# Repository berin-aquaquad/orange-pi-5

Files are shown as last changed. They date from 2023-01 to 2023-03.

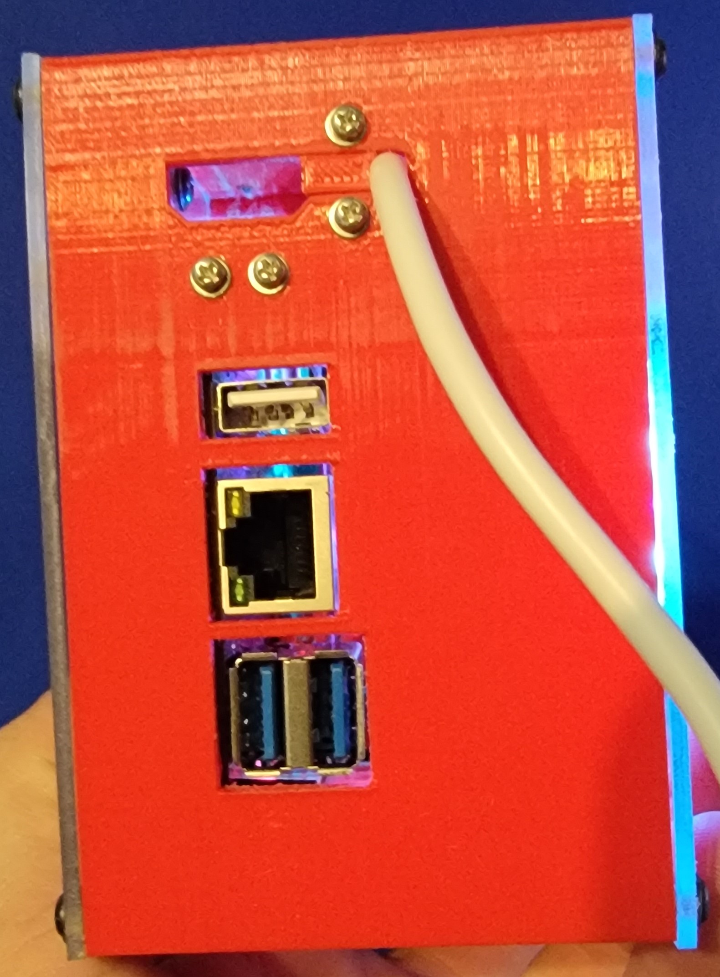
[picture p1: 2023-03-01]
design concept pipeline/20230228_231924.jpg

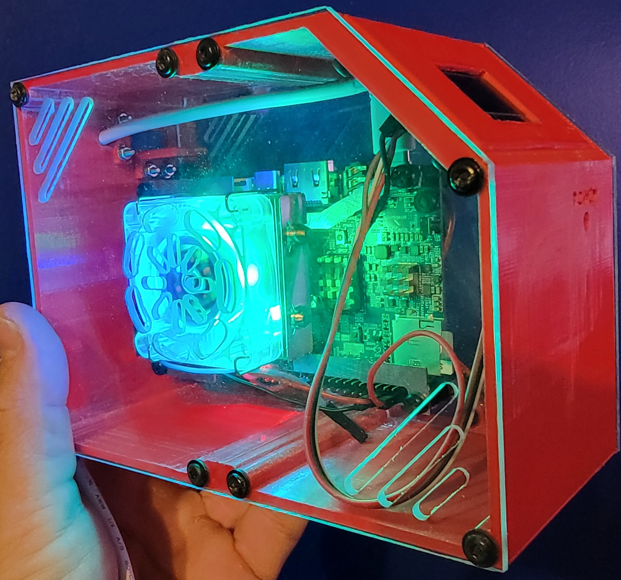
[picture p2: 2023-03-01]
design concept pipeline/20230228_231910.jpg

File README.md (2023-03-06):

Best source for current content from me https://forum.armbian.com/topic/25673-orange-pi-5-opi5-micro-desktop-case-design/

# As of right now this is a working design for anyone wanting to build the case. Everything matches up and everything works, questions PLEASE ask.

20230228_231910 thumb jpg 945669c564e5bb9a0a729d5997930626

# ORANGE-PI-5  I have updated the case with a new front half design, and many other adjustments.

# KEEP CHECKING BACK I UPDATE THIS GIT REPO OFTEN.

# FIRST OPI5 IN THE WORLD WITH A REAL MOUNTED ICE TOWER HEATSINK! Now that my OPI5 has a full suite of heatsinks on it. My next focus is on starting the build of the micro desktop case and OS. I believe the first part I'll build is the SBC mounting plane. That will give me something to mount to then I'll start the main body 3d print.

20230212_163206 thumb jpg 70dcd27b7984e3ebd21cffe2945fdb69

opi5microdesktopupdated2 thumb jpg 56bcd5c85741f7769b6156b93f30e681



opi5 micro desktop back and side view

opi5 micro desktop heatsink standoff mount bracket

opi5 micro desktop dimensions
The core body is 68mm wide. The lower standoffs are 6mm, the upper standoffs are 10mm

opi5 mounted to plane

OPI5 open micro desktop case design, with a split body for two options. Main feature printable on smaller cnc machines, second feature is the ablity to have custom front and back desgined panels. Some may need ports on the back of the shell. Other people may desire features like lcd(s) and headers that are on the back to be on the front. Its a more useful design.

2/18/2023 Bunch of updates and new features and corrections, standard filler for 45 degree area is done. This allows anyone to make a custom insert design, I have one design done so far which is the i2c lcd and a blank version. I have updated the side covers to remove the circle holes on one side and relocated the vent intake for the tower cooler on the other side. I have added a CR2032 BATTERY holder for RTC features. The battery holder is just a pocket for a real button battery holder. The idea is to solder wires and install it into the case holder All files affected by adjustments should be updated.

2/15/2023 I am redesigning the 45 degree area with a universal filler plate that can be designed to one's needs. I think at this point I'm going to add a folder as designs in the pipe for images only.

2/11/2023 So got my new 3d printer, ended up buying one from a big box office store, amazon lost the one I ordered delivering it to the wrong address?? I just printed the AFT half of the main micro desktop body. I have found a few things to be slightly off and am making cad corrections now. I'm also adding an insert filler setup that will allow the power cord to go though the aft of the case. I need to find the HDMI ribbon cable setup I used on an other project. (https://photos.app.goo.gl/GvprVxFfbKAWY7VR7 "raspberry pi fiberglass shell") I am doing some adjustments to the placement of the port openings and the ports drawn on the board are off slightly. I may post updates tonight. ******** 5pm update I've been cad'ing for the past few hours after taking my fam to the beach for a while, lot of fun but LOTS of Man o war littering the beach. updates should be uploaded around 11 ********** 11:14pm I believe I have uploaded all updated files.

2/6/2023 CAD files have been updated and uploaded, unless I missed something everything should be updated corrected with the latest corrections. .rsdoc .stl .dxf files and some images have been updated.

2/5/2023 I have milled the corrected back plane and it came out perfect see too pictures when I get to posting. Also I just discovered I made a small not error but over site. One of the back plane mounts is in the wrong location so you can not remove the back plane with the opi5 mounted IF that screw is populated. Because it is under the opi5 board under the stacked USB ports. I'm updating the cad drawing and I'll post the correction some time soon. That will be a correction to the master .RSDOC cad file, and to the back plane DXF file and the back half of the micro desktop tower shell dxf and .rsdoc files when I finish the correction. Look for all 3 files to have the same time date update when updated. If the git repo dates are not updated too today I have not updated yet.

2/4/2023 I have ordered a (https://www.amazon.com/gp/product/B076WXR8N9 "I2c OLED Display 0.96") and I just ordered a new much larger 3d printer. I will be making a custom front shell half version when I get the display. Again this case design is a modular setup so it can be custom to one's needs for the front and back halfs. As well as the width can be adjusted as desired.

2/3/2023 I have finally cut the side covers out of acrylic, I have posted the updated DXF files in the gcode folder as well as posting an image.

1/28/2023 Family visiting and other events and work sorry been quiet for a while. I have just finished a bunch of updates to the cad draws. Fine tuning to the measurements for the heatsink bracket and the mount plane hole spacing for the OPI5, and the mount hole placement of the OPI5 board its self. Sadly I can not find a picture with a measurements breakdown of the opi5 mounting holes. I have milled the back plane but the holes are just off by a hair, it looks good though.

1/22/2023 late tonight. I just updated the the cad files to fully realize the dimentions of the standoffs and other aspects. The CAD drawing should be a first version final draft as of now. The core body has been made a little wider. The core 3D printed body is now 68mm's wide. It was 62mms before getting the replacement standoffs. This also means the placements of the port openings for the OPI5 on the back of the case have been relocated by a few MM as well. JUST A REMINDER this case design is special. The shell is a split body for two reasons, different versions of the front and back halfs of the core micro desktop can be created. And the full sized case can be printed on smaller footprint 3d printers as small as a 110mm x 110mm print area.

1/22/2023 12:30pm ? I have done nothing I just tried turning the opi5 on one last time and it just randomly posted.... I am so confused right now I have done nothing changed nothing. I just plugged it in and it just posted and booted into the SD card ubuntu build???? WTF.... Odd thing is I'm getting no HDMI video but I am getting usbc-hdmi.... Well these problems have destoryed my chance to get anything done this weekend. To much time lost to total failure. About 2 hours after I stopped trying to turn it on, I came back to it and just plugged it in. The red light came on and it just started booting. I DONT GET IT.

* 1/22/2023 I have been endlessly overwhelmed by my employer. I was planning on starting to build parts for the case yesterday 1/21 SAT., but I was tasked with 
* designing and 3d printing. Inclusion mold parts for a many millions of dollars luxury yacht. That being said I just got a chance to test my opi5 today sunday. And I * apear to have a DOA dead unit out of the box. As of this moment this project is on hold indefinitely until I get a working OPI5. I am very angry and very pissed off. * My unit will not power on period, no signs of life nothing. Its 100% dead out of the box.

1/21/2023 I will be cutting the acrylic panel(s) today starting with the SBC mount panel first. I have not cut 1/8th acrylic on my cnc before so I may run into a bit of trial and error figuring the best milling bits out feeds/speeds.

1/16/2023 Ok looking for feed back https://www.amazon.com/Duttek-Degree-Extension-Motorcycle-Dashboard/dp/B08RRYMXB6 https://www.amazon.com/Poyiccot-Extension-Female-Extender-Straight/dp/B086YBP5VW Two examples of USB-C adapter which do you guys like? also USB-c to the front or back of the micro case? 
*************** This is the spacer/stand off kit I have purchased https://www.amazon.com/dp/B08DMSNB8X This is the kit for mounting the OPI5. All spacings will be based off of these when I get them. stay tuned. 6mm and 10mm standoffs are used from this kit. As well as one of the screws with two plastic nuts for holding the m.2 NVME drive.

1/17/2023 BIG update I have just mounted my heatsink to the OPI5 it LOOKS AMAZING. Now that I have my heatsinks mounted My next step is moving to to software.

1/15/2023 Unbelievable, I have to order a kit of plastic stand off mounts for the OPI5 project. I have a huge kit and its just ….. ? GONE ? In any case the brackets are built sanded and “dry” fitted. Its a perfect fit but still dont have the standoffs,so I cant assemble anything. Very pissed off, I’m 99.999999 sure I tossed the sorted box last year along with a bunch of trash and excess useless empty sorting boxes of like size kind. By design the bracket I designed and built clears everything. No feature on the OPI5 SBC is blocked between connectors and buttons.

1/14/2023 tonight, I found the screws I need FUI the cooler I described uses 2.5mm screws. I have picked up some 1/16th sheet steel and will try my hand and milling the brack design with my cnc. Its not designed for steel but is ok for aluminum. I do have some 4 flute bits so we shall see. **** tonight update part two, cutting steel sheet metal on my cnc machine...??..??? and its going REALLY well. I will post photos when the milling job is done. ******** last post for the night just before midnight. The steel frame bracket has been cut and is pictured in the cad/gcode folder have a look. Its the first noncad image I've posted.

1/14/2023 small update, my aluminum block has been cnc milled (I'll post new photos soon keep checking). I need to get some longer screws that match the heatsink and some sheet metal to create a bracket to keep the heatsink in contact with the processor (gravity strain relief). I wish I had access to a fiber or co2 metal cutting laser to make a perfect bracket. The standoff heatsink is to allow the small stick-on heatsink kit that adds cooling to the other chips on the OPI5. I also added a new folder with gcode files for the heatsink spacer block.

1/11/2023 Small update, finally got a chance to start building the aluminum spacer heatsinc block, I'll post pictures when able.

(1/7/2023) New updated cad drawing. I got my RPI4 "ice tower cpu cooling fan" heatsink. I have done the CAD adjustments I need for it to be installed. I am now creating a custom SPACER aluminum block and attachment bracket so it can even work with the OPI5. 
At this point if anyone has interest in adjustments Please contact me.

This is an ongoing project and I'll be uploading updated cad draws as they are available and pictures of the latest adjustments. If anyone has a request please send me a message via twitter #Berinmoney I'll respond as time allows. I'm also on orangepi.org forum and armbian forum. When I get closer to a final version I'll add images showing dimensions.

This design was created using Designspark mechanical https://uk.rs-online.com/web/generalDisplay.html?id=designspark%2Fdesignspark-mechanical 
I have not built the design yet as of the current date whatever today is. I will post about the start of the build when I start. I'm adding locations for all of the missing I/O to the shell as I find good parts to do so with, or learn of features. I just finished building the cad model 12/31/2022. I have currently left it as an open canvas design. The shell itself can be modified if so desired to be a mono body. Currently it's designed as a split body to be able to be printed on smaller 3d printers. The outside covers left and right are acrylic. The Mount that the OPI5 mounts to is acrylic as well. This design expects the two side panels and the sbc mount panel to be 3d printed or cnc cut or laser cut. The rest of the shell is to be 3D printed. Enjoy and please tag me as the original designer. 
FYI I'm looking for details on the OPI5. The OPI5 has an onboard RTC real time clock. and there are two test pads next to it one "grd1" the other "RTC1". That MUST be for a battery backup. I can find no details on what kind of a battery setup is needed. According to the schematic "RTC1" will be HOT with 5v DC when the SBC is running. What battery setup may be used on this? Any help would be wonderful.

Planned design additions for consideration: I need feedback on the listed or suggestions if not listed. I can create it in cad but I need dimentions to items of consideration.

* Headphone jack front or back, maybe a custom PCB to breakout audio/mic and split to a backside of the desktop header.
* USB on front.
* All other headers LCD 1 2, CAM 1 2 3, UART.
* Stats LCD on front.
* 3D printed power button to press power button on OPI5 motherboard.
* GPIO header for external access, "custom design or standard?? I need a web link example".
* RTC battery holder to make use of the onboard RTC.
* RGB Micro Desktop case LIGHTING options?
* Lithium battery backup power pack

Manuals https://drive.google.com/drive/folders/1Bre2q0bGgXQuQlYaYDMvwstpvtHLmcgX?usp=share_link
* Looking at the PDF manual the headphone jack has a mic connector for external micrphone support.

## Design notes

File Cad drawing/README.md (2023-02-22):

# I plan to rearrange the GIT a bit to make it a little more orginized. 
opi5 micro desktop updated
# I have updated the cad draw and stl files for the OPI5 micro desktop as of 1/22/2023 the cad drawing should be final first version. Any changes after this will be feature changes and have there own sub folder for front half and back half of the split body OPI5 Micro Desktop. 

# KEY NOTE! I have elected to use two standoff types to mount the OPI5 and the rpi heatsink. The opi5 standoff is a 6mm with male thread standoff, the heatsink standoff uses a full female 10mm standoff. The 6mm male standoff is screwed into the 10mm standoff through the four OPI5 mount holes. To remove the OPI5 from the shell you have two choices, remove the screws from the backside to release the OPI5 keeping the standoff setup intact on the opi5. The other option is to remove the screws from the mount plane that screws to the OPI5 Micro Desktop from the right hand (backside) side. Removeing the OPI5 in this manner will leave the OPI5 attached to the mounting back plane.

An RSDOC file is the custom CAD file format for DesignSpark. It's a full 3d file format. Designspark is very powerful CAD software that is also free and on par with fusion360. 

The OPI5 mainboard in my cad drawing should be 99.9% accurate with all of the "headers" and ports that are relative to this desktop tower build currently.

The HDMI port on the back is expecting a ribbon cable extension HDMI adapter, amazon sells them places like that.

I need to find out what all of the features of the audio jack are before I adjust or add a standard short extension and screw tensioner port for audio.

I will add links to products if people do not have them on hand as time goes on.

# The GCODE folder contains files for the aluminum heatsink standoff and the mounting brackets for the heatsink. The micro desktop V1 folder contains the core micro desktop files for 3d printing or editing the two halfs for personal needs. Please give me credit on the design thanks.

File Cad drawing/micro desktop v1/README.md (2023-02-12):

# Mind numbing fixes, adjusted the LCD mount measuring directly. The amazon source measurment files were way way way off. Some how I got the foot print for the RTC battery backup wrong way under sized. Male female coupler for the front/back of the case just dont mesh together so increased the size difference male/female. I'll do a cut down test print for them before I do my next .... test ... print. I believe at this point the latest files I posted should be the first really accurate version. ******* I cant help my self had to come back to it for a little bit, I just sanded down and fit the two halfs of the shell together what I have. They are non useable but it did give me some insite and will make for a good working photo maybe later today. The OPI5 mount plane fits perfect in the case. I did just discover the vent hole for the FAN is off by a little so that will be one of the next updates when I get the side cover mounted with some screws. Then I can do a 100% measurment location X/Y. Funny thing is its not off at all the heatsink tower does not land on center.

These are the core desktop cad files. The STL files are ready for printing and seperated. If someone wants to modify the shell halfs, the master cad file is in the orange-pi-5
/ Cad drawing directory. Files in this folder are the core shell files only.

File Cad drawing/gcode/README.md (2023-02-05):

heatsink block milling path

The TAP file is a GCODE file for running a cnc machine. I have posted a file for both the heatsink block and mount brackets. If anyone has a cnc machine that can mill aluminum. This file expects a 1/8th milling bit, it expects a block of aluminum 12mm or .5" thick. The top of the tooling material is prob to zero. The tool path will mill below the thickness/depth of the stock during the two hole milling cycles and the final cut out. Account for those actions, the feed rate is 20mm/min. With out a clearing system like forced air and or flood coolent/lube, the deep cuts may need to be manually cleared. If the aluminum chips are not cleared then the the milling job may risk aluminum chip welding. That never ends well.

The .E10 file is an ESTLcam file. I love ESTLcam, everything about it is easy. There are a few areas I'm not a fan of but that could have been designed different but I can work with it.
It does have some small issues and there is a bug in the coding that has to do with standard/metric units option-settings. I've asked the creater manytimes only to be brushed off. As long as the software options settings are correct on the UI everything is accurate. The problem is a "rounding" issue to the .xxx point rounding up. so... .005 would be rounded upto .01. You can see the issue with gcode output in regards to a tooling path and bit size.

steel bracket cnc cut out

Micro desktop sides cut finally. I have modified the DXF files only so far. The main .RSDOC file I'll update when I get around to it, but I changed the dimentions of the 45 degree vents and spacing. I also added straight lines in the vents that needed them. That allows anyone who plans to mill the design. To preform an engrave or straight cut rather then milling the "pocket" or hole function. I may post the GCODE files if I get any requests, if interested its setup for a 1/8th or 3.125mm two flute upcut bit running 15k rpm or greater. With a feed rate of 50mm/min two passes, then a finishing cleanup pass full depth at 150mm/min. Its true I could mill it faster BUT I mounted it with dbl sided foam tape. Not worth the risk of deflection warping the cut.



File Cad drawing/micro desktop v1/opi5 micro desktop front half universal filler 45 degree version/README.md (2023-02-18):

This is a custom front half of the OPI5 shell that has a universal insert located in the 45 degree area of the case. There is a blank filler and one that uses the i2c LCD. The lcd designed for is this one https://www.amazon.com/dp/B076WXR8N9 "i2c OLED Display 0.96 Inch" The pinout is part of the cad drawing.
The blank filler can be modified for anything custom, I did design the filler with the idea of using brass thread inserts with 2.5mm screws.

There is a CR2032 battery holder location. This is designed for a ******* real ******* vertical pcb mount battery holder as pictured.
opi5 micro desktop rtc battery

5a1bccd3-be66-45ea-b0ee-86c1367f1945
The idea is to feed the fine wires through the hole as pictured.opi5 micro desktop rtc battery wire hole at base

Then solder the wires to a "KEYED JST" connector so its not able to be plugged in backwards. With out using a jst connector or like connector, the OPI5 would be hard wired to the RTC battery and can not be removed from the case. There are two test pads on the back of the OPI5 for RTC. One is labled "RTC" for +3v cr2032 power and the other is labled "GRD" DO NOT MIX THESE UP! Wires soldered to these tiny points should be strain reliefed with hotglue or epoxy dots and zip tie the wires to the OPI5 standoffs. In the picture below you can see the RTC and GND test pads on the back side of the OPI5 with a red arrow pointing at them.

pi-5-bottom-view

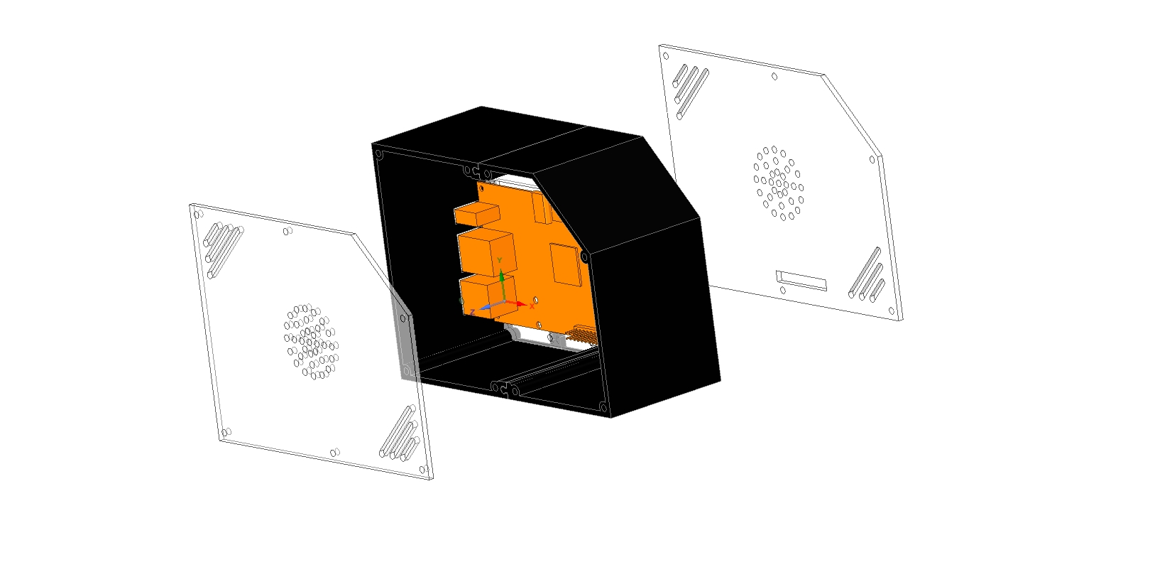
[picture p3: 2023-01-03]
opi5 micro desktop design vents and GPIO added.jpg

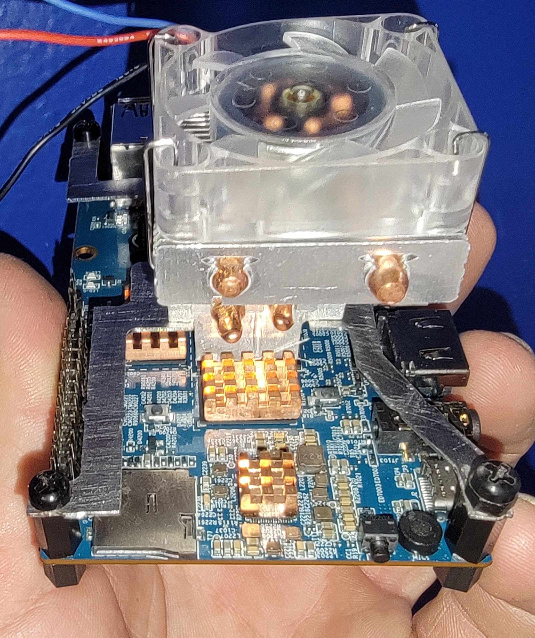
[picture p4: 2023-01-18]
front top down.jpg

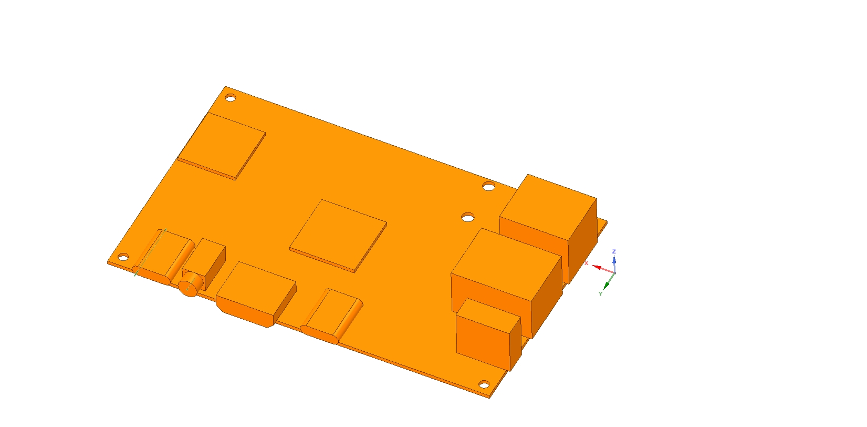
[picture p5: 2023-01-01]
opi5 mainboard.jpg

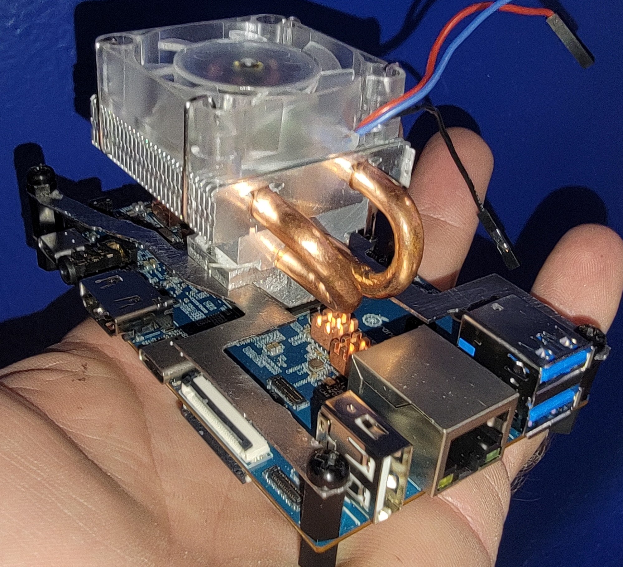
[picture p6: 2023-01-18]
back corner left.jpg

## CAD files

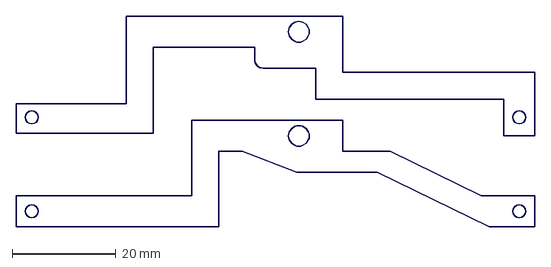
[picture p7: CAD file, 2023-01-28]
Cad drawing/gcode/heatsink bracket.dxf
100.0 x 40.6 mm

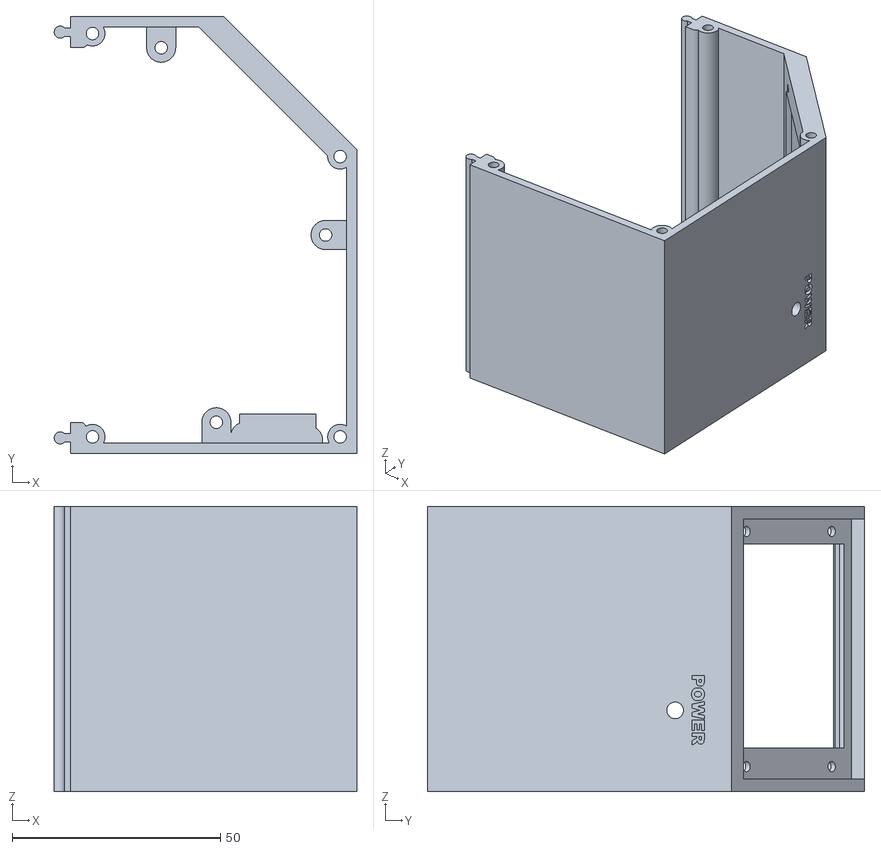
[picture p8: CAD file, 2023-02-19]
Cad drawing/micro desktop v1/opi5 micro desktop front half universal filler 45 degree version/opi5 micro desktop front half custom 45 degree insert.stl
72.7 x 105.0 x 68.5

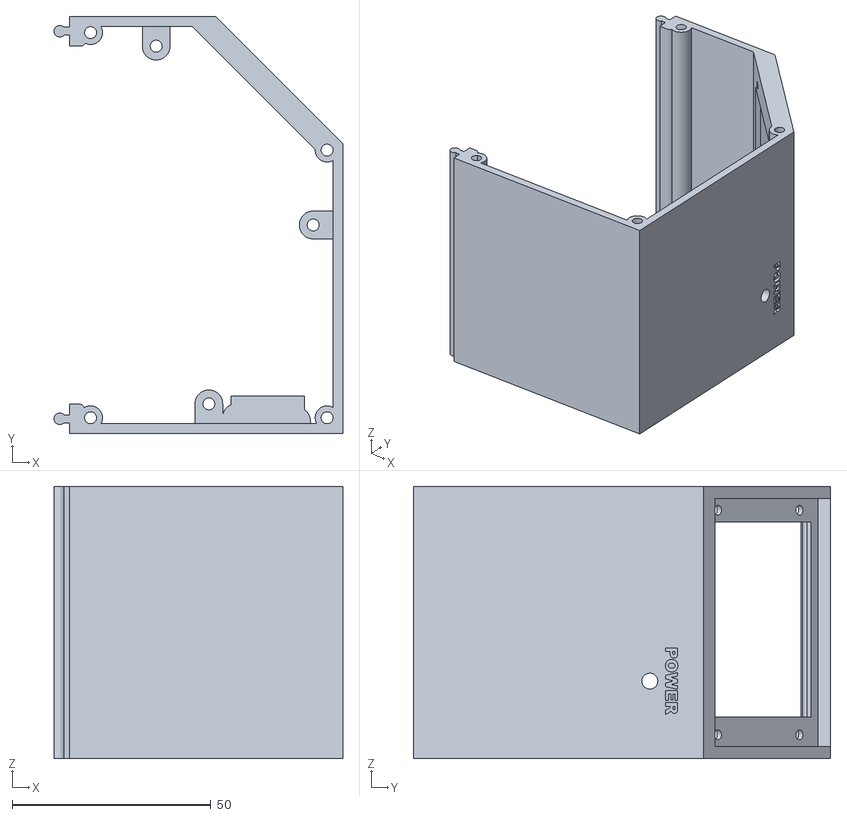
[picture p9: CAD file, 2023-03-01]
Cad drawing/micro desktop v1/opi5 micro desktop front half.stl
72.7 x 105.0 x 68.5

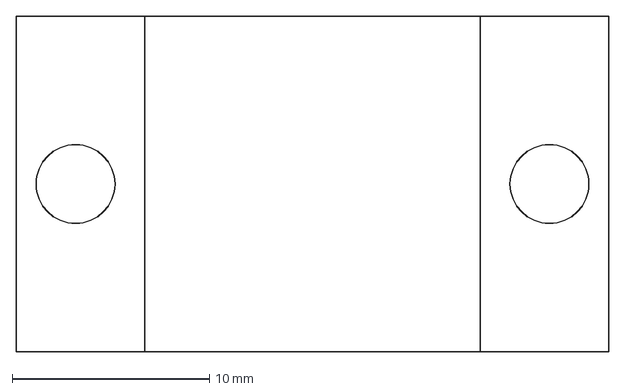
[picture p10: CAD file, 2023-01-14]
Cad drawing/gcode/2D heatsink.dxf
30.0 x 17.0 mm

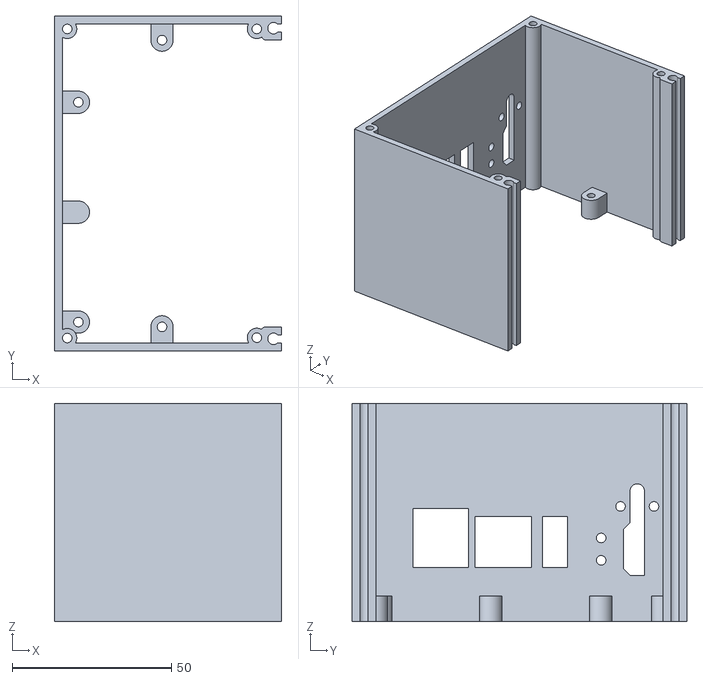
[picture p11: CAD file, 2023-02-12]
Cad drawing/micro desktop v1/opi5 micro desktop back half.stl
71.3 x 105.0 x 68.5

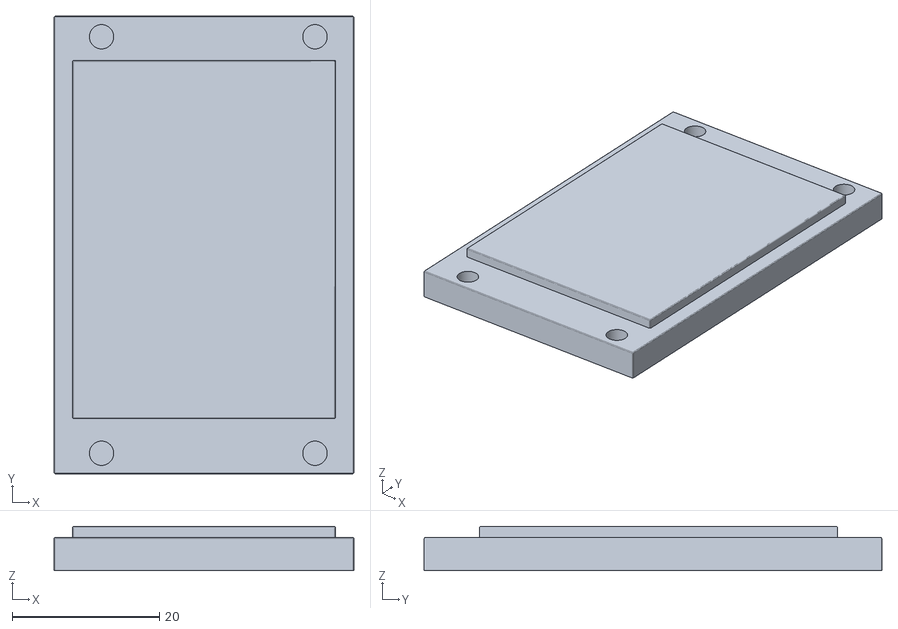
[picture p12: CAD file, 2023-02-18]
Cad drawing/micro desktop v1/opi5 micro desktop front half universal filler 45 degree version/custom 45 degree insert blank canvas version.stl
40.7 x 62.1 x 6.00

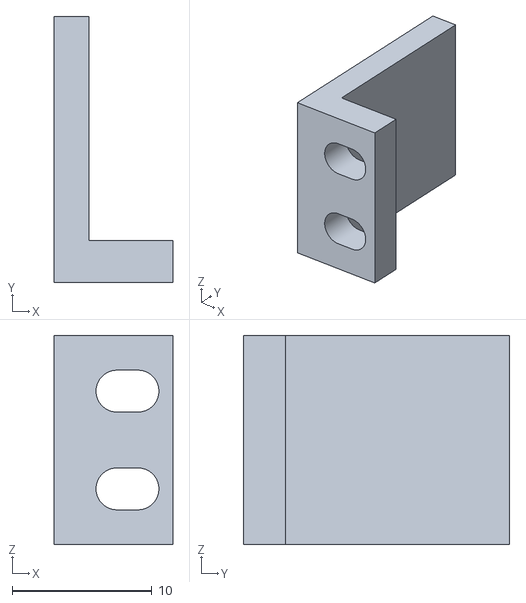
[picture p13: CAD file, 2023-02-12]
Cad drawing/micro desktop v1/hdmi support.stl
8.50 x 19.0 x 15.0

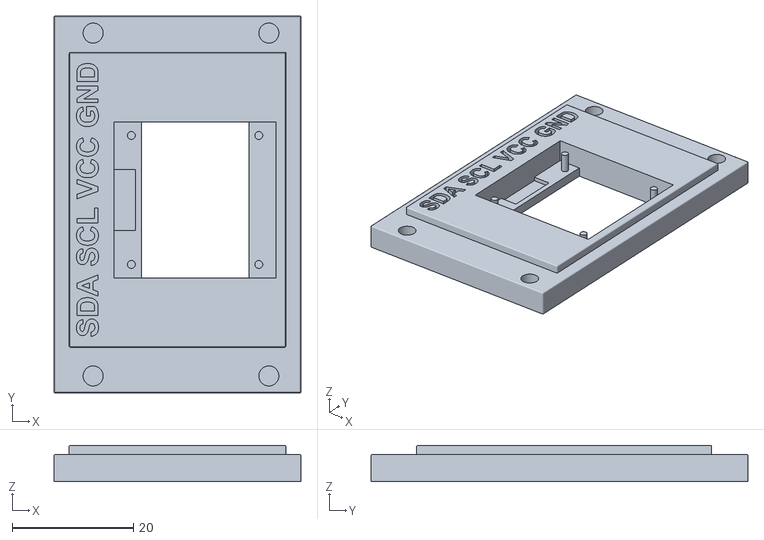
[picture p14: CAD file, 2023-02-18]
Cad drawing/micro desktop v1/opi5 micro desktop front half universal filler 45 degree version/custom 45 degree insert i2c lcd version.stl
40.7 x 62.1 x 6.00

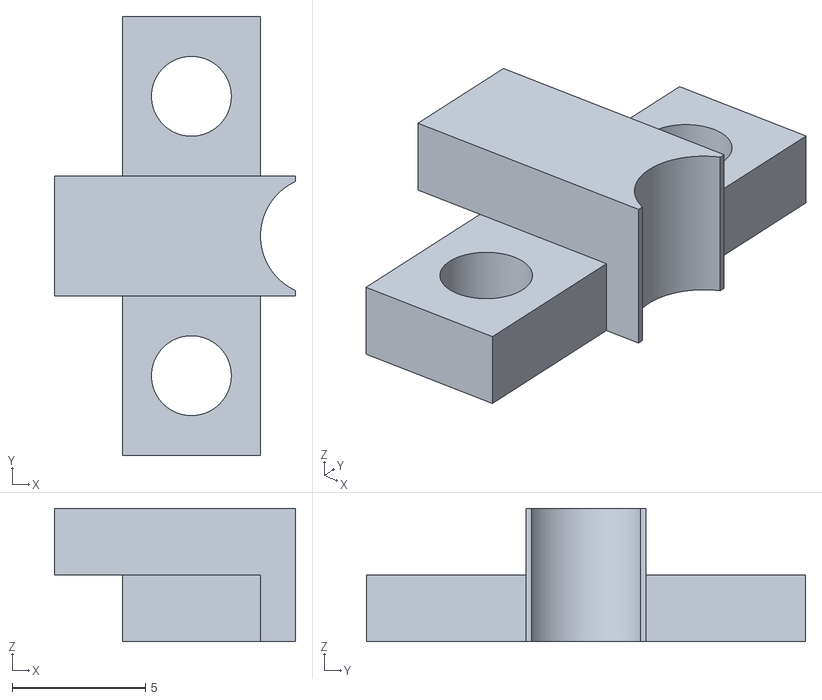
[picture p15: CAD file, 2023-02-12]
Cad drawing/micro desktop v1/usb power wire hole filler.stl
9.07 x 16.5 x 5.00

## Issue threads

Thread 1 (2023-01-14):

M.2 2280 support

uqtsherr, 2023-01-14:
Given the case is oversized, consider support typical 2280 SSDs.

I have a really basic Creo rest which bolts to the 2230 and 2242 mount points and provides a mount hole for a 2280 at the optimum bolt height. It could either be included or incorporated into the PCB mounting solution.

berin-aquaquad, 2023-01-15:
I dont have one of those on hand. I'll look into it. The pcb I'm talking about is just for the head phone jack and power button and RTC battery. tiny DIY level stuff. My case is 135mm long along the base. The 2280 ssd is 22x80mm That could fit in the bottom easy. The top at the shortest is 104mm long. Vertical its 100mm tall. As is the 2280 would fit anywhere. IMO a remote header would be the best choice.

Closed 2023-02-19.

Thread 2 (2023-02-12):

SBC file?

asid61, 2023-02-12:
I can see all the case files but there doesn't seem to be a file with just the SBC anywhere?

berin-aquaquad, 2023-02-12:
Just dbl checked everything is there. What "file" are you looking for? Under the folder "/cad drawing/" there is a file a file called  " opi5 micro desktop.rsdoc" using Designspark Cad software You can look at the entire drawing. All broken out files come from that master file. Using Designspark dbl click on the SBC using the arrow/select icon. then right mouse and HIDE OTHERS. You will be left with just the OPI5 SBC. Everything is still listed in the tree to the left. If you want to Un-hide anything.

berin-aquaquad, 2023-02-13:
What is your plan with the SBC cad drawing its self. also assume its 98% accurate I only find errors as I'm building the hardware its self. Thousands of people have downloaded my design but I've see almost no responce.

asid61, 2023-02-26:
I was planning on using the SBC cad to make my own casing actually, but I couldn't find it so I ended up looking elsewhere. The assembly didn't load quite right for me because I had to convert it to another format.

berin-aquaquad, 2023-03-01:
Designspark is a great cad software. The main cad file has everything in it assembled. And everything is in the build tree. There are no missing parts. OPI5MICRO DESKTOP.RSDOC Is the main file.  Again try downloading and using the free cad software designspark. It is as powerful as fusion360. The pay for version is called Spaceclaim.

samuk, 2023-05-20:
Could you output this file as a .stl please?

samuk, 2023-05-20:
Or maybe a .DXF https://grabcad.com/questions/can-anyone-change-a-rsdoc-file-to-a-stp-or-igs-file

I don't have windows so can't install DesignSpark

Closed 2023-02-19.

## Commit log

2023-01-06 Add files via upload
    Just adding an STL version for people to have more options.
2023-01-06 Create cad file.nfo
2023-01-08 Update and rename cad file.nfo to README.md
